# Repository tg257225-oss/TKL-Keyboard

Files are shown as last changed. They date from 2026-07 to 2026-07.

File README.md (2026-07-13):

# TKL Keyboard
An F12 TKL Multi-Layout Hotswap keyboard, designed in KiCad10 and Fusion360. Everything in the 'Production' folder of this repository should be everything you need for the physical parts of this keyboard. Gerbers file can be provided to JLCPCB (or others) for them to manufacture the PCB. The STP files are used to 3D print the top case, bottom case, and plate.

KiCad Renders:
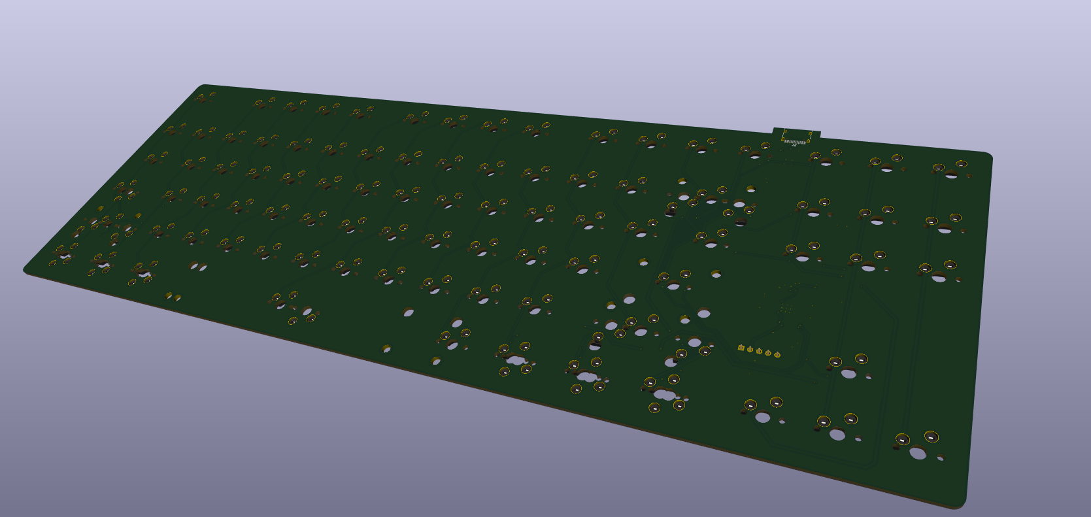
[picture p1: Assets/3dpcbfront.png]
PCB Front
### 
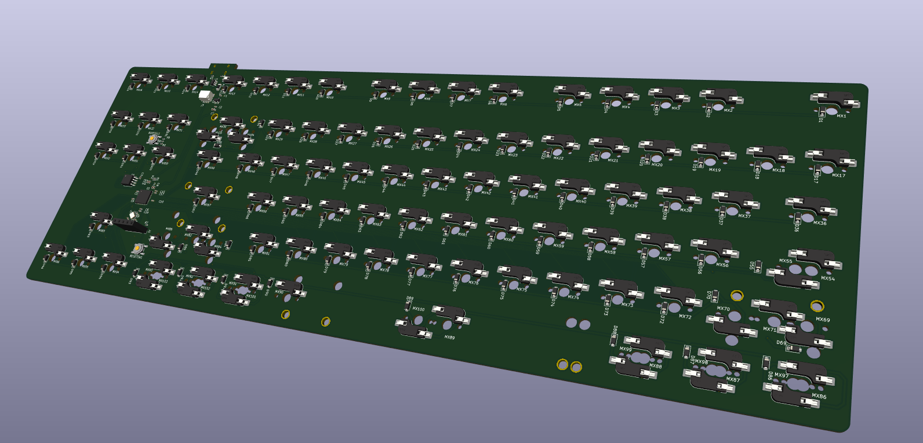
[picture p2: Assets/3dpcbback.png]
PCB Back
### 

Keyboard Case:
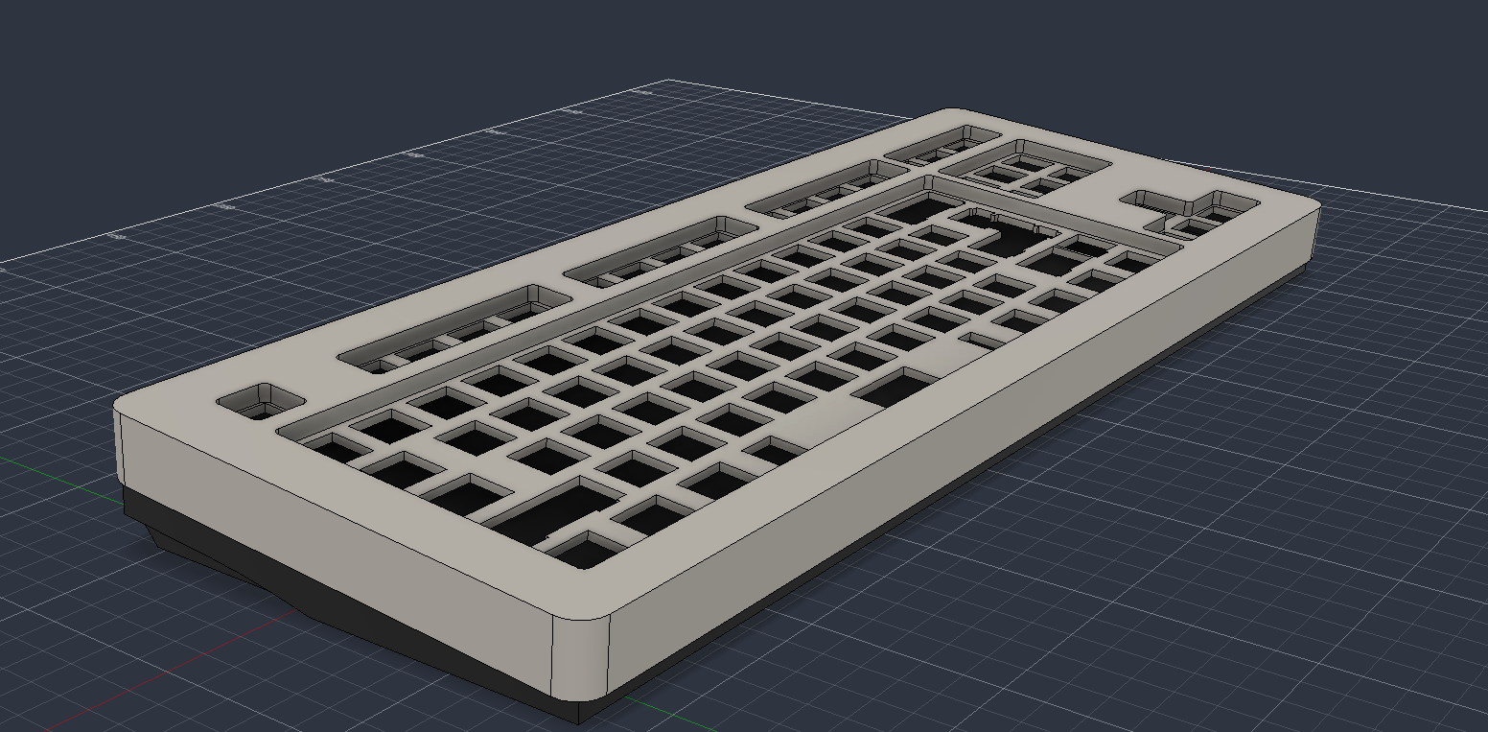
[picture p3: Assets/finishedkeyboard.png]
Entire Case
### 
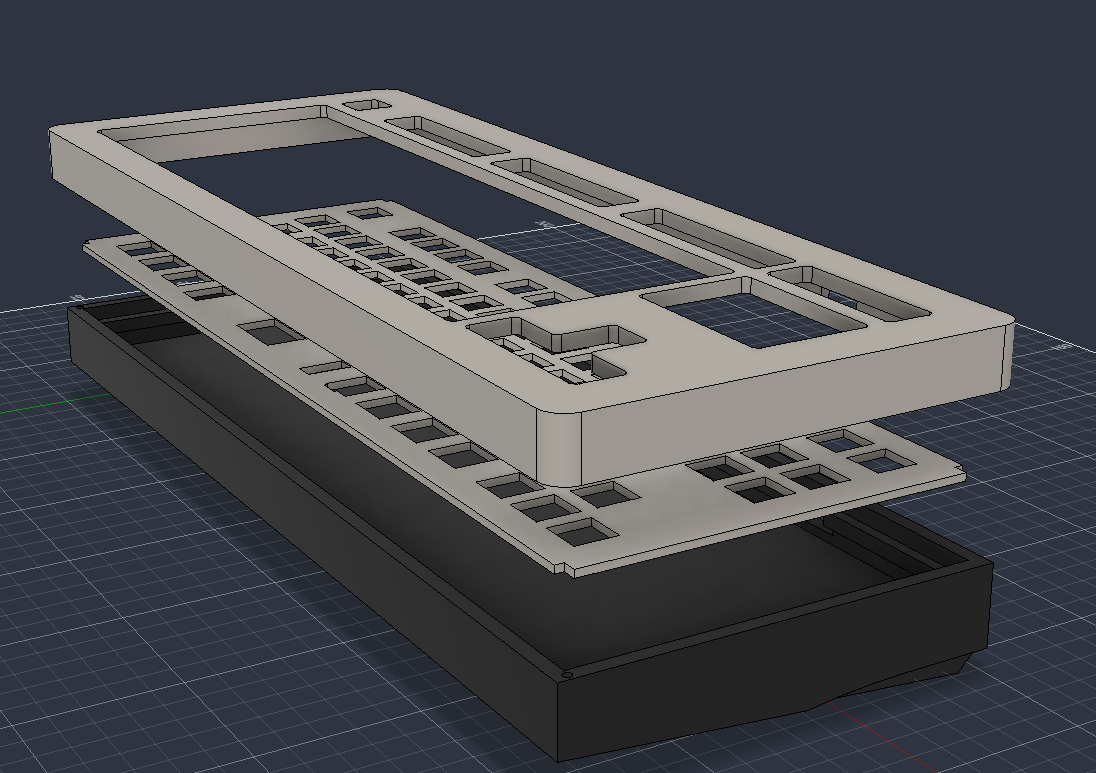
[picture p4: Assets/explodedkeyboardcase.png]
Exploded Case
### 

## Features
* RESET Switch - allows you to reboot the keyboard's processor 
* BOOTSEL Switch - Allows you to load custom firmware onto the keyboard
* Uses the RP2040 MCU
* Uses Kailh Hotswap Sockets
* 16Mib Flash Memory
* 12MHz Crystal
* USB-C Port
* ESD Chip to prevent damage from electrostatic discharge
* Supports ANSI/ISO

## Multi-Layout Support
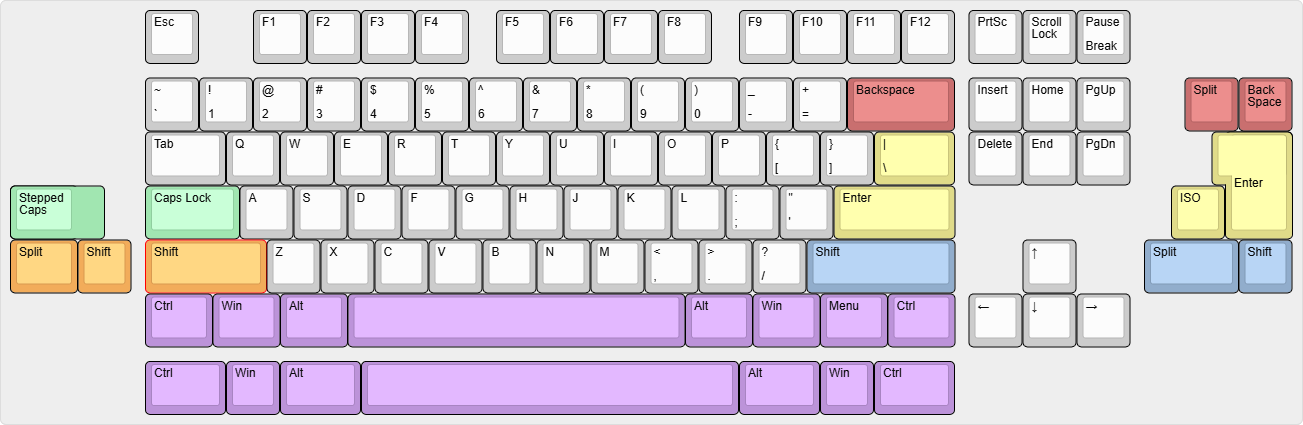
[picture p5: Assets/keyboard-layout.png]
Multi-Layout
### 

## Firmware
Here's the basic keyboard layout (the one included in the 'Firmware' folder):
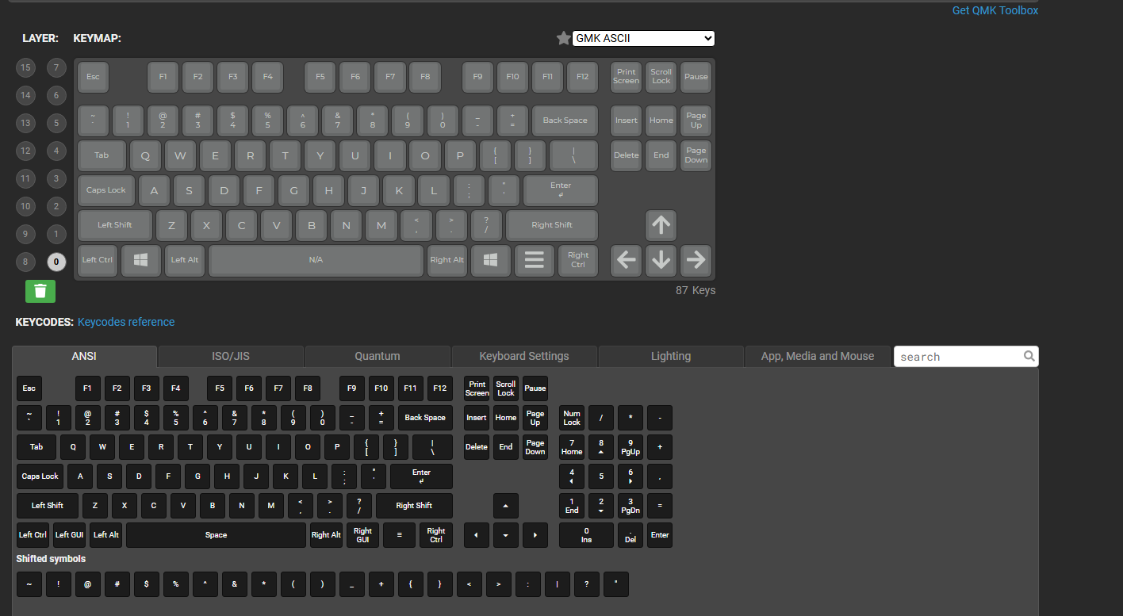
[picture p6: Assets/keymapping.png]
Keyboard Layout
### 
You can edit it by uploading the JSON file in the 'Firmware' folder into QMK and making the necessary changes for the layout you want to use.
### Flashing Instructions
1. Hold the BOOTSEL switch while plugging the board into the computer. Your computer will recognize the keyboard as a new USB flash drive.
2. Drag the .uf2 firmware file onto the drive which will flash and reconnect as your keyboard.

## BOM for everything but the PCB
These are just items I found online, obviously not everyone will have to buy everything or may find things cheaper.
| Item | Price | 
| --- | --- |
| PORON Foam 3mm (https://kineticlabs.com/misc/kinetic/keyboard-case-foam) | $11.99 | 
| PORON Switch Pads 120pcs (https://www.thockking.com/products/120-pcs-poron-switch-pcb-pads-keyboard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) | $5.95 |
| PORON Gasket Pack (https://sneakbox.com/products/poron-gasket-pack-for-ava) | $2.50 |
| Rubber Feet for Grip 16pcs (https://www.amazon.com/Non-Slip-Replacement-Compatible-Keyboard-Appliance/dp/B0D4YMSKB4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) | $5.99 |
| PLA Jade White Filament - Refills (https://us.store.bambulab.com/products/pla-basic-filament?id=40475106640008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) | $19.99 |
| PLA Dark Gray Filament - Refills (https://us.store.bambulab.com/products/pla-basic-filament?id=42844629008520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) | $19.99 |
| Kailh Box White Mechanical Switches 108pcs (https://www.amazon.com/Zjmehty-Mechanical-Keyboard-Switches-Waterproof/dp/B0CBPQGBSF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) | $32.99 |
| Black on White Double Shot ABS Keycap Set 150pcs (https://mechanicalkeyboards.com/products/tai-hao-150-key-abs-double-shot-cubic-keycap-set-black-on-white) | $23.99 |
| M3x25mm + M3x35mm Screws (https://www.amazon.com/VGBUY-443Pcs-Assortment-Printer-Washers/dp/B0D14BC8QS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) | $9.99 |
| Stabilizers (https://minokeys.com/products/aeboards-staebies) | $20.00 | 
| Total: | $147.39 | 

## Assembly (a little unconventional but I plan on making things easier in the future)
1. Case Dampening - Cut the 3mm PORON case FOAM to fit and lay it fly inside the 3D-printed bottom case. There should be a 1.5 mm air gap between the foat and the hotswap sockets to allow for gasket flex. Extra foam can be placed but they shouldn't be overpacked.
2. PCB + Plate - Apply the PORON switch pads to the the PCB, install the stabilizers, and snap your chosen switches into the plate to secure them. Align the switch pins with the Kailh hotswap sockets and press the plate and PCB together.
3. Gasket Mounting - Apply the PORON Gaskets to all four margins on the plate, one on the top of the plate and the other on the bottom, creating a sandwich. These gaskets should rest on the shelf located in the bottom case.
4. Case Fastening - Place the top case over the assembly and secure it by driving screws through the matching holes on the bottom case. This current case design calls for M3 x 23mm screws on the front end of the keyboard and M3 x 34mm screws on the back end, which are not standard screw sizes and are hard to source. Trim M3 x 25mmm and M3 x 35mm screws accordingly if the custom sizes cannot be found. Future changes to the design will utilize standard screw sizes. On the front end, the rubber feet should be placed over the screws due to how the hole is, the rest can go wherever you'd like.
5. Keycaps - Add your desired keycaps according to the chosen layout and plug in the keyboard.

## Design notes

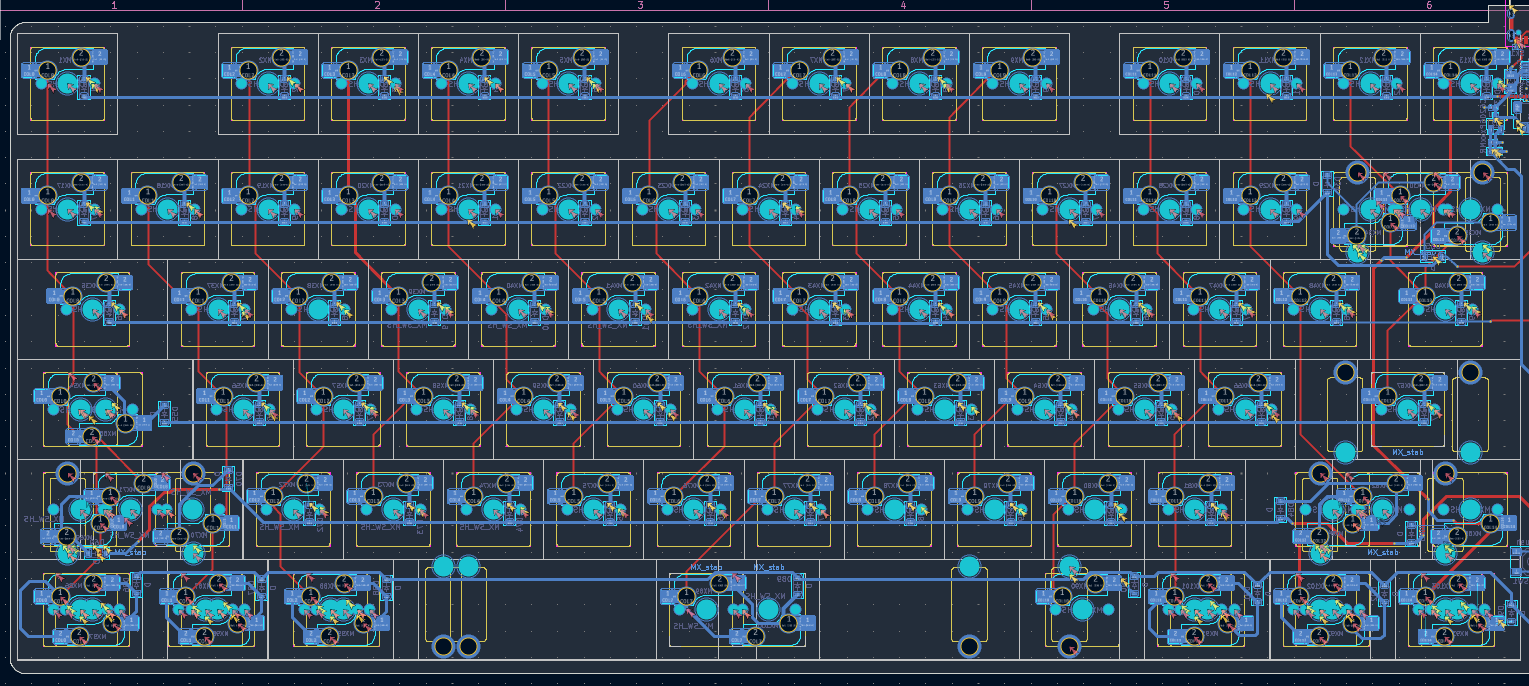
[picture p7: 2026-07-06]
Assets/matrixwip.png

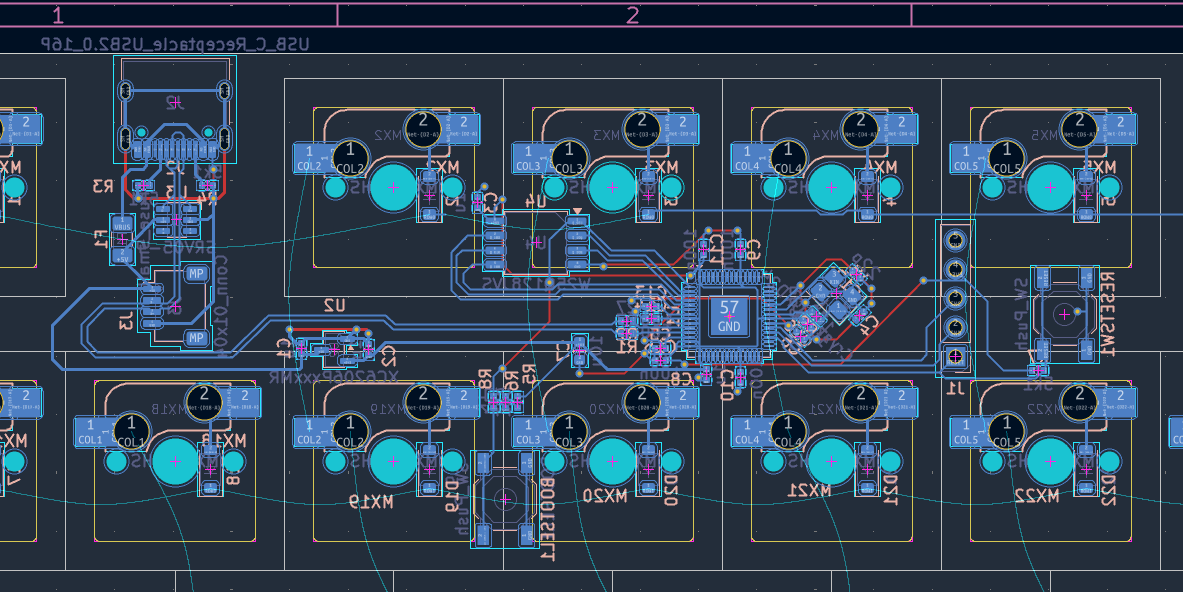
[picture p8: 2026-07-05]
Assets/failnumber1.png

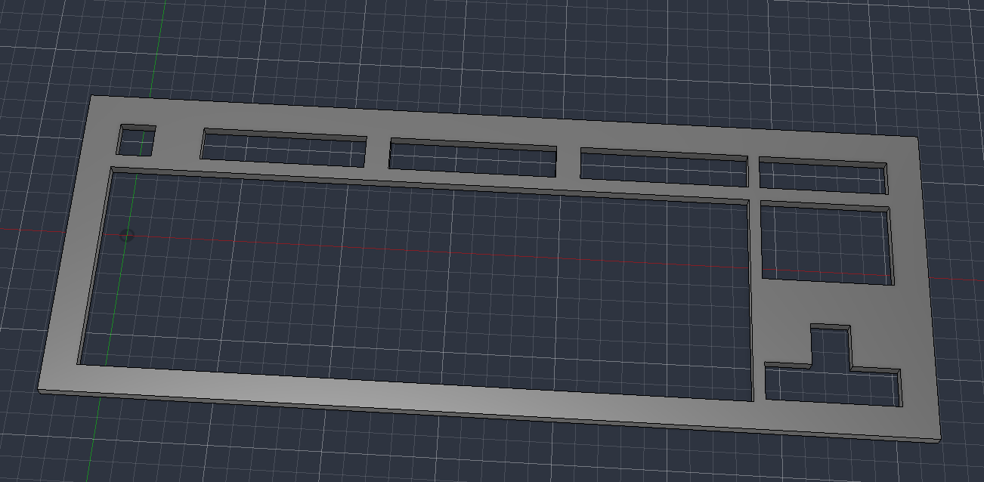
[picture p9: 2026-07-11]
Assets/topplate.png

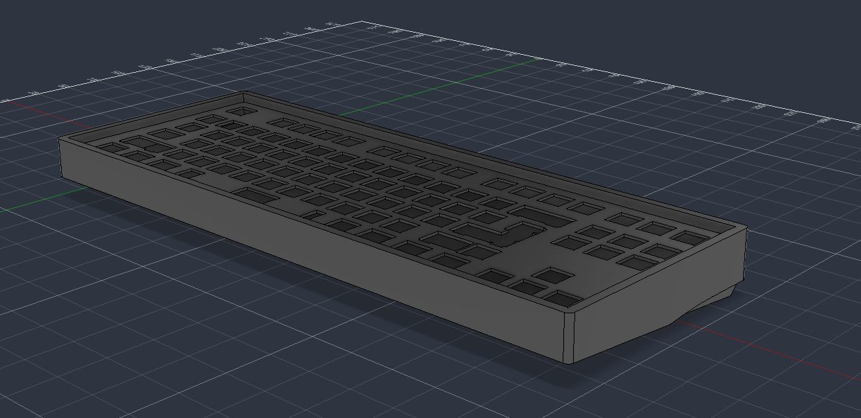
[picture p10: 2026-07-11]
Assets/caseplate.png

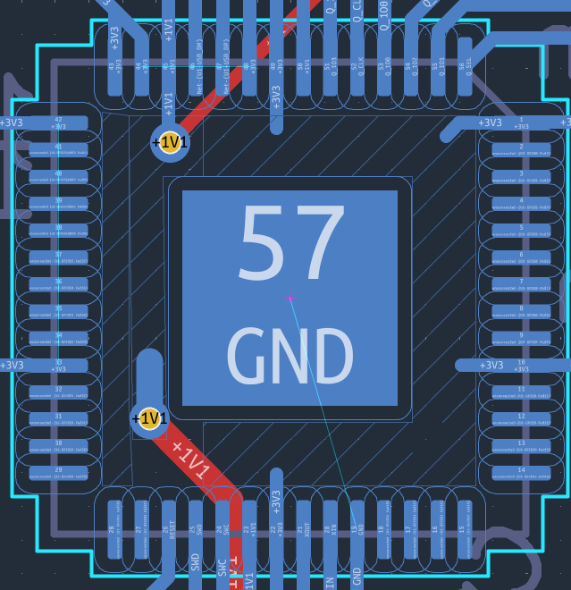
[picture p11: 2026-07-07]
Assets/copper zone.png

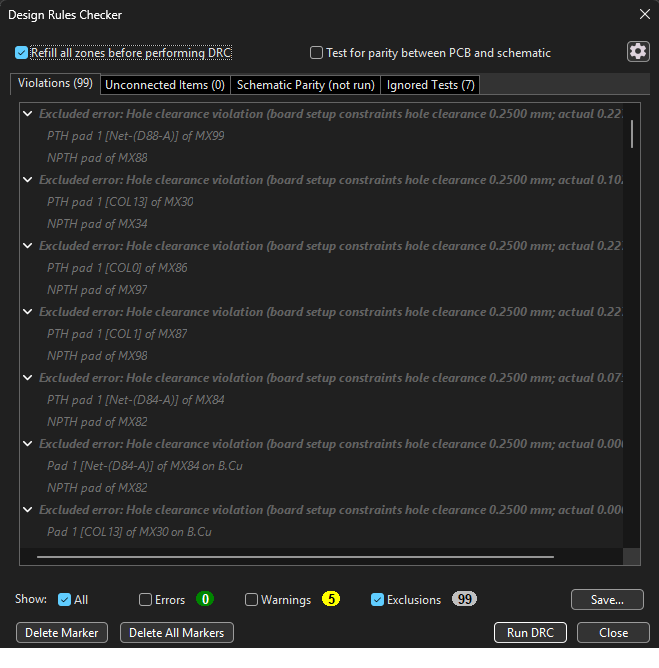
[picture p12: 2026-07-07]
Assets/practically clean drc.png

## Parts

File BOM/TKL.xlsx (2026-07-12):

Reference Designators | Qty | Value / Description | Package | Manufacturer Part Number (MPN) | Estimated Unit Cost (USD) | Estimated Total Cost (USD)
BOOTSEL1, RESETSW1 | 2 | SW_Push (Tactile Button) | SMD | TL3301AF260QG | $0.26 | $0.52
C1, C2, C5, C8 | 4 | 1uF Ceramic Cap | 402 | GRM155R61A105KE15D | $0.02 | $0.08
C3, C6, C9, C10, C11, C13, C14, C15, C16, C17 | 10 | 100nF Bypass Cap | 402 | CC0402KRX7R9BB104 | $0.01 | $0.10
C4, C12 | 2 | 22pF Crystal Cap | 402 | CC0402JRNPO9BN220 | $0.01 | $0.02
C7 | 1 | 10uF Bulk Cap | 603 | GRM188R61C106MA73D | $0.05 | $0.05
D1-D90 | 90 | Isolation Diode | SOD-123 | 1N4148W-7-F | $0.06 | $5.40
F1 | 1 | Fuse_Small (500mA PTC) | 1206 | MINISMDC050F-2 | $0.45 | $0.45
J1 | 1 | Conn_01x05 (Pin Header) | 2.54mm | 61300511121 | $0.35 | $0.35
J2 | 1 | USB_C_Receptacle_16P | Mid-Mnt | TYPE-C-716-A01602P64 | $0.85 | $0.85
J3 | 1 | Conn_01x04 (JST SH) | 1.00mm | SM04B-SRSS-TB(LF)(SN) | $0.40 | $0.40
MX1-MX99 | 101 | MX Hotswap Sockets | Kailh | CPG151101S11 | $0.15 | $15.15
R1, R2 | 2 | 27 Ohm Resistor | 402 | RC0402JR-0727RL | $0.01 | $0.02
R3, R4, R5, R6, R7 | 5 | 5.1k Ohm Resistor | 402 | RC0402FR-075K1L | $0.01 | $0.05
R8, R9 | 2 | 1k Ohm Resistor | 402 | RC0402FR-071KL | $0.01 | $0.02
S1-S6 | 6 | PCB Stabilizers | Clip-in | Mechanical Item Only | $1.20 | $7.20
U1 | 1 | RP2040 Microcontroller | QFN-56 | RP2040 | $0.92 | $0.92
U2 | 1 | XC6206P332MR LDO | SOT-23 | XC6206P332MR | $0.18 | $0.18
U3 | 1 | SRV05-4 ESD Protector | SOT-23-6 | SRV05-4.TCT | $0.25 | $0.25
U4 | 1 | W25Q128JVS Flash | SOIC-8 | W25Q128JVSIQ | $0.95 | $0.95
Y1 | 1 | Crystal 12MHz | 3225 | ABM8G-12.000MHZ-18-D2Y-T | $0.55 | $0.55
TOTAL ESTIMATED COST |  |  |  |  |  | $33.51

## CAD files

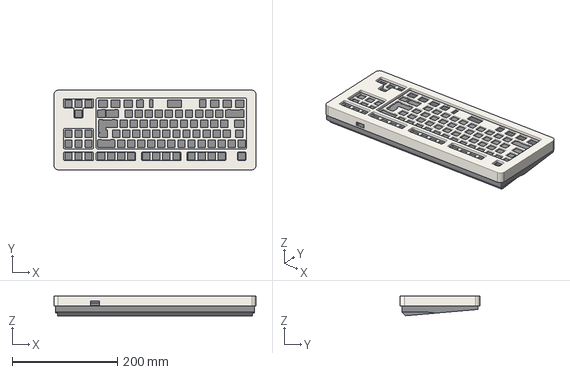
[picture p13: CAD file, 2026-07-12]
CAD/TKLKeyboard.step
383.0 x 151.0 x 37.1 mm

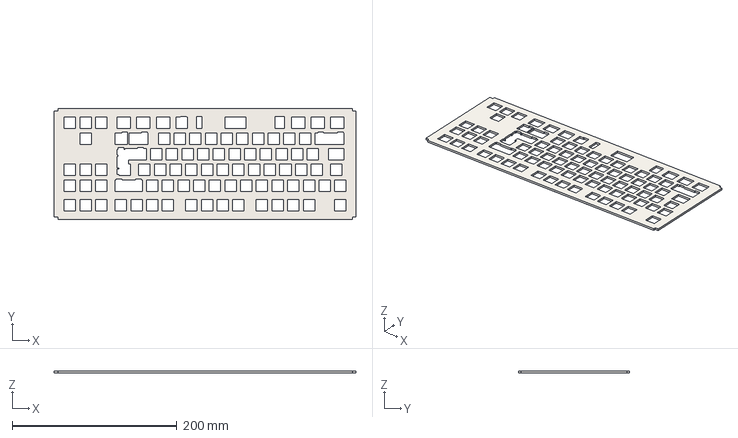
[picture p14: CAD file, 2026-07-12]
Production/Plate.step
367.0 x 135.0 x 2.50 mm

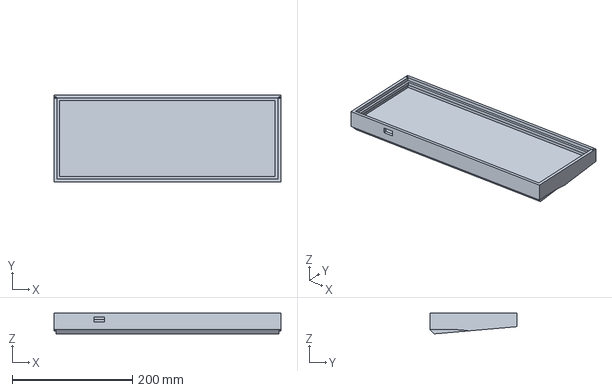
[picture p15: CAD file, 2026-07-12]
Production/BottomCase.step
377.0 x 145.0 x 34.6 mm

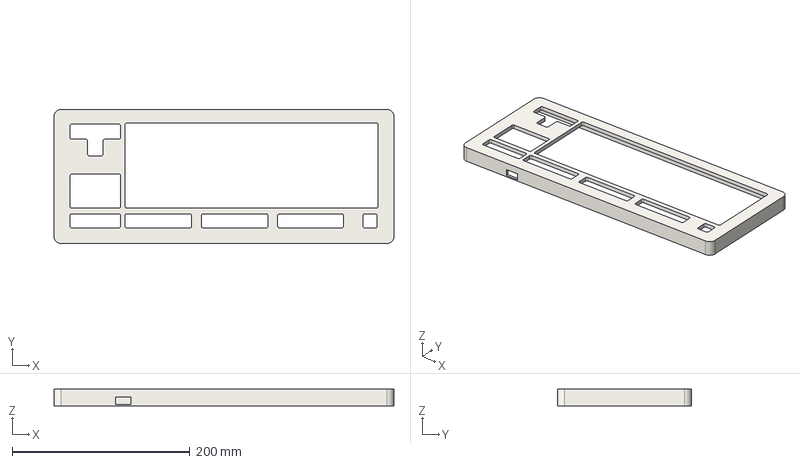
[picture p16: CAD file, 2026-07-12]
Production/TopCase.step
383.0 x 151.0 x 19.0 mm

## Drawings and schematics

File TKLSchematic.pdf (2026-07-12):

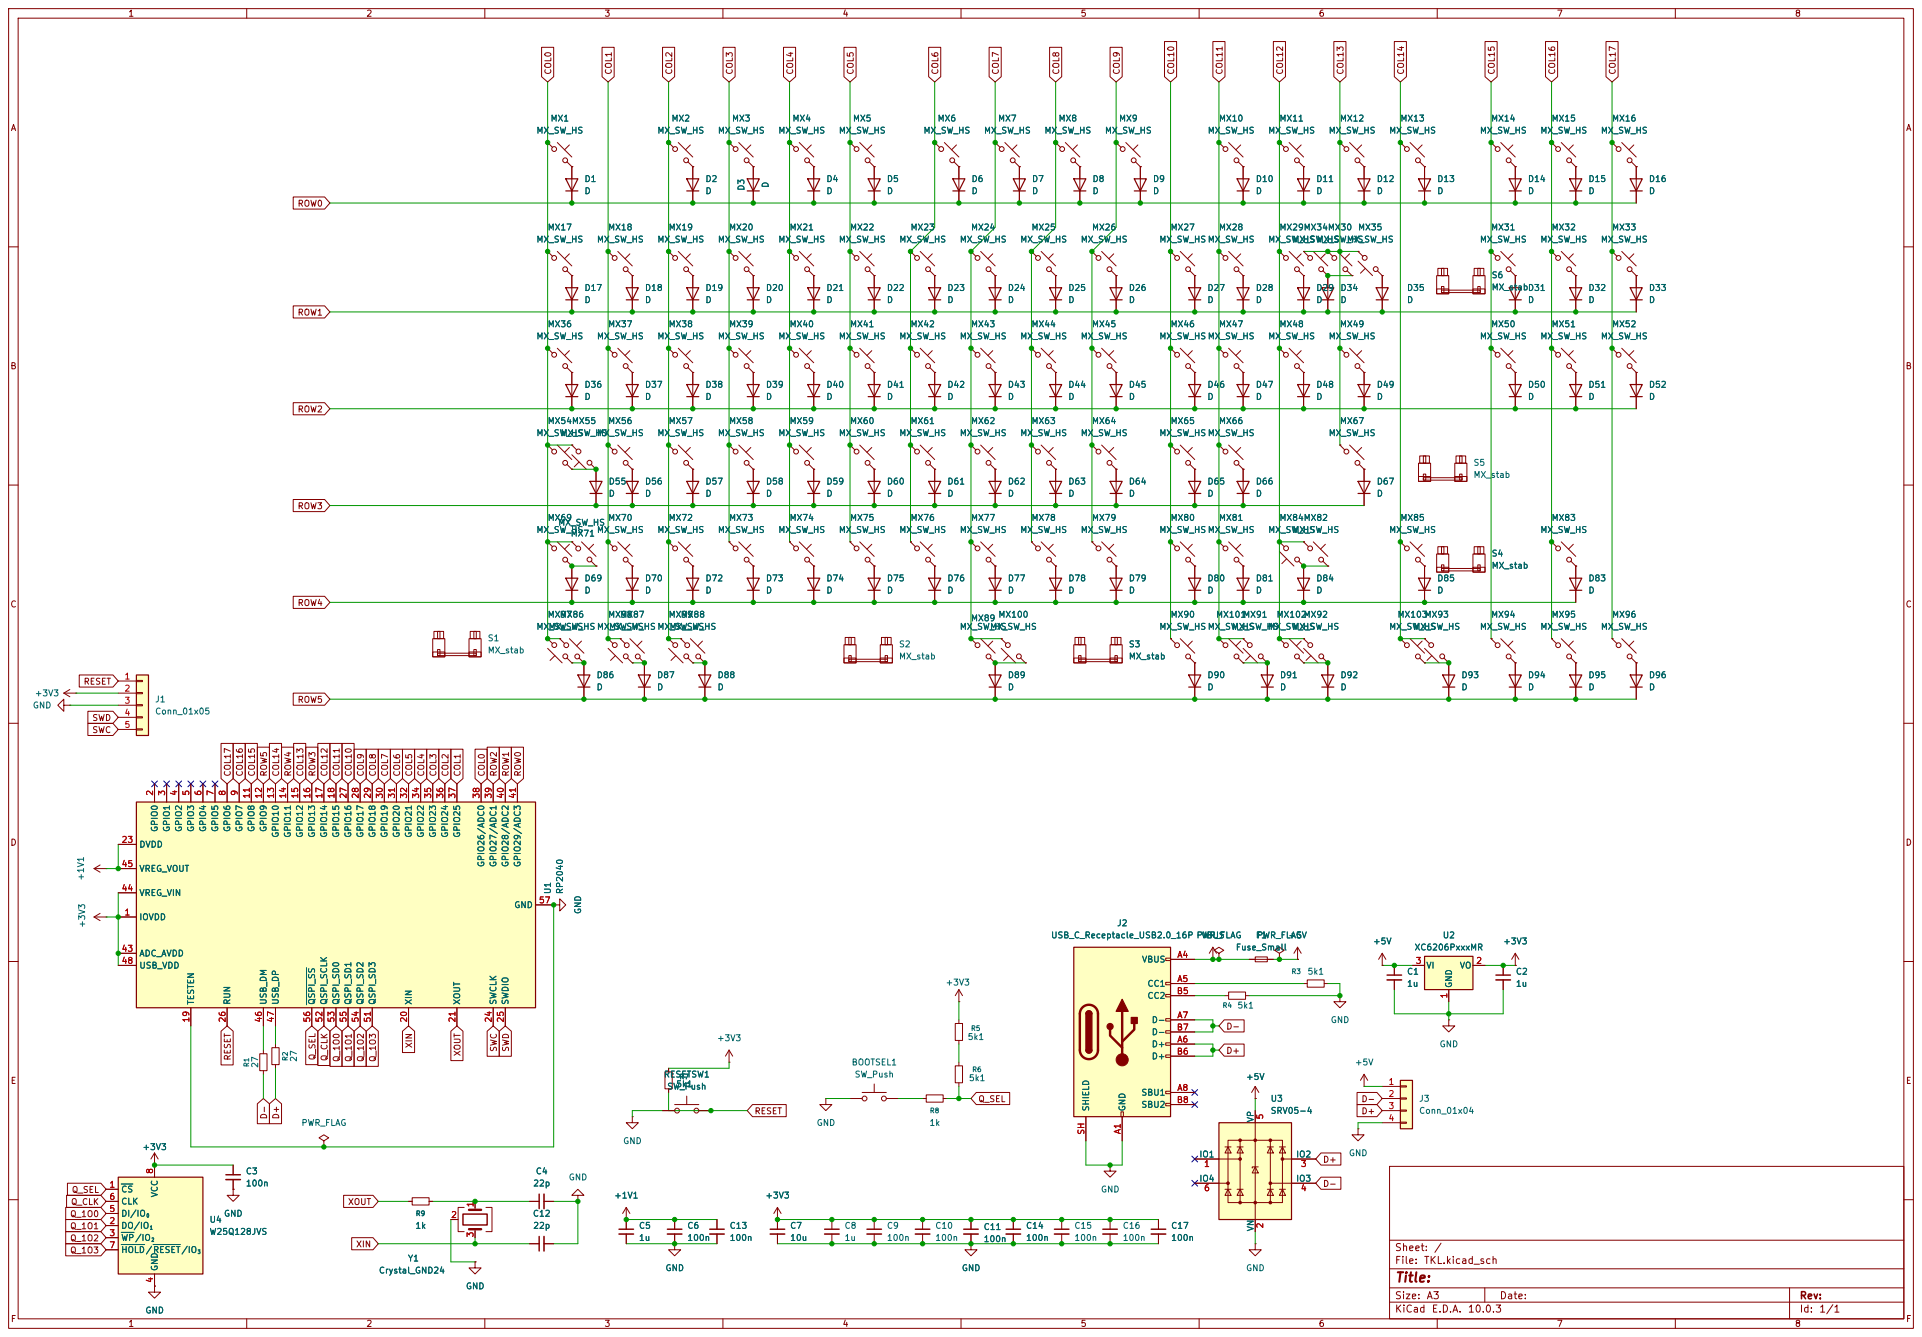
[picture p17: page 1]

9 GPIO8 11 GPIO9 12 GPIO10 13 GPIO11 14 GPIO12 15 GPIO13 16 GPIO14 17 GPIO15 18 TESTEN 19 XIN 20 XOUT 21 DVDD 23 SWCLK 24 SWDIO 25 RUN 26 GPIO16 27 GPIO17 28 GPIO18 29 GPIO19 30 GPIO20 31 GPIO21 32 GPIO22 34 GPIO23 35 GPIO24 36 GPIO25 37 GPIO26/ADC0 38 GPIO27/ADC1 39 GPIO28/ADC2 40 GPIO29/ADC3 41

4 DI/IO0 5 CLK 6 HOLD/RESET/IO3 7 VCC

Size: A3 | Rev: | F Date:
KiCad E.D.A. 10.0.3 | Id: 1/1

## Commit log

2026-07-12 Rename project to TKLKeyboard and add renders
    Updated project title and added KiCad renders section.
2026-07-12 Fix image link for PCB front render in README
2026-07-12 Fix header formatting for PCB Front image
2026-07-12 Update README to include entire case image
2026-07-12 Add exploded case image to README
2026-07-12 Enhance README with manufacturing details
    Added information about Gerber files and STP files for manufacturing and 3D printing.
2026-07-12 Add BOM section for components used
    Added Bill of Materials (BOM) section to README.
2026-07-12 Update BOM table headers in README.md
2026-07-13 Revise BOM in README with new components
    Updated BOM with additional items and links.
2026-07-13 Add BOM for keyboard components with pricing
    Added a BOM section with prices for various components.
2026-07-13 Update README with assembly instructions and parts list
    Added assembly instructions and updated parts list with prices.
2026-07-13 Revise flashing instructions and BOM details
    Updated flashing instructions for clarity and added stabilizers to the BOM.
2026-07-13 Update case fastening instructions in README
    Added instructions for placing rubber feet over screws on the front end of the keyboard.
